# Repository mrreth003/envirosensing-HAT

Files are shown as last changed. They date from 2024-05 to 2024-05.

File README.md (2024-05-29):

# Envirosensing HAT PCB Design Group Project (EEE3088F)

## Design Team

- Ethan Morris (MRRETH003)
- Ethan Meknassi (MKNETH002)
- Moutloatsi Setlogelo (STLMOU001)

## Project Overview

Our project involves designing a proximity sensor surveillance device using a HAT (Hardware Attached on Top) powered by either a microcontroller or a battery. The HAT utilizes a PIR motion sensor to detect the presence of a person or animal, triggering a buzzer to sound an alert. Detection logs are stored and can be accessed by the user.

## Hardware Requirements

To operate this device, you will need the following hardware:
- **Power Source**: Either an STM32000 microcontroller or an 18650 battery.
- **USB Cable**: Male USB A to Male Micro USB B Cable for data retrieval.
- **Computer**: For data retrieval and battery charging.

## Hardware Setup

### Microcontroller Power Setup
1. Place the microcontroller under the device using the inner set of connectors.
2. Connect the 5V pin of the microcontroller to pin "J3" on the device. Pin "J3" is the leftmost pin on the third row of connectors when the device is in its default position (buzzer at the top left).

### Battery Power Setup
1. Insert the 18650 battery into the battery holder.
2. Connect the USB to Micro USB cable to the device and your computer for data retrieval or battery charging. The battery should be placed in the position indicated by the red rectangle in the attached picture.

## Basic Operating Instructions

1. Power on the device using the battery.
2. Create movement close to the device (e.g., wave your hand 5-10 cm away from the device). The buzzer should beep, indicating the device is operational.
3. To retrieve the detection log, connect the device to a computer using the USB to Micro USB cable.

## License

The license information for this project can be found in the Git repository.

[Project Repository](https://gitlab.com/mrreth003/envirosensing-hat/-/tree/main/)

Kind Regards,

Ethan Morris, Ethan Meknassi, and Moutloatsi Setlogelo

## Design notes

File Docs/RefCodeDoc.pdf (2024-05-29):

main class
Function | Description
MX_I2C2_Init(void) | Initializes the I2C communication port, lines and respective pins. I2C Channel 2 used to communicate with the Ambient Light Sensor with port B, pin 11 as the SDA line & port B, pin 10 as the SCL line
MX_GPIO_Init(void) | Initializes the GPIO Configuration. GPIO port C, pin 15 set to output mode.
MX_ADC_Init(void) | Initializes the ADC Configuration. Port C, pin 15 configured to ADC input
SystemClock_Config(void) | Configuration of the system clock.
MX_TIM2_Init(void) | Initializes the Timer Configuration channels for PWM generation. Port A, pin 1 used to generate pwm signal.
MX_USART1_UART_Init(void) | Initializes the USART Configuration. Port A, pin 10 set to Rx line & port A, pin 9 set to Tx line.
debugPrintln(UART_HandleTypeDef *uart_handle, char _out[]) : void | This function is used to send text data to the USB-COM port of the computer via the debug adapter. It has the following attributes: a pointer to the UART instance to write data, the output string in the form of a char and also it terminates the string using newline and carriage return commands.
main(void) | Houses and allows for execution of other functions. Allows for modulation within the code structure, improving debugging capabilities.
Error_Handler(void) | This function is executed in case of error occurrence.
assert_failed(uint8_t *file, uint32_t line) | User can add his own implementation to report the file name and line number.

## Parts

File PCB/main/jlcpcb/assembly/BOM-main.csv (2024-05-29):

Comment | Designator | Footprint | LCSC
2.2uH | L1 | L_0805_2012Metric | C1043
Buzzer | BZ1 | SPKR_PKM13EPYH4002-B0 | C128650
USB_B_Micro | J5 | USB_Micro-B_Molex-105133-0031 | C132563
TLV70012_SOT23-5 | U4 | SOT-23-5 | C134139
10uF | C8 | C_1206_3216Metric | C13585
TPS61230DRC | U3 | Texas_S-PVSON-N10_ThermalVias | C139626
CH340G | U10 | SOIC-16_3.9x9.9mm_P1.27mm | C14267
100nF | C20,C30,C31,C32,C33,C34,C35,C36 | C_0603_1608Metric | C14663
1u | C10,C7,C9 | C_0603_1608Metric | C15849
1k | R15,R16 | R_0805_2012Metric | C17513
100k | R17,R18 | R_1206_3216Metric | C17900
NPN | Q5 | SOT-23 | C20526
AO3400A | Q6 | SOT-23 | C20917
13k | R23 | R_0603_1608Metric | C22797
1M | R5 | R_0603_1608Metric | C22935
2k | R24 | R_0603_1608Metric | C22975
4K7 | R20,R22 | R_0603_1608Metric | C23162
10k | R2,R4 | R_0603_1608Metric | C25804
MAX232 | U11 | SOIC-16_3.9x9.9mm_P1.27mm | C26860
4.7uF | C1,C3,C5 | C_1206_3216Metric | C29823
LTC4054ES5-4.2 | U1 | TSOT-23-5 | C32574
LTR-553ALS-01 | U8 | LTR553ALS01 | C492375
10nF | C28,C29,C6 | C_0603_1608Metric | C57112
AT24C256C-SSHL-T | U9 | SOIC-8_3.9x4.9mm_P1.27mm | C6482
Q_PMOS_DSG | Q4 | SOT-23 | C8492
D_Schottky | D5 | D_SOD-323 | C8598
12MHz | Y1 | Crystal_SMD_3225-4Pin_3.2x2.5mm | C9002
Conn_01x33_Female | J1 | PinHeader_1x33_P2.54mm_Vertical
BK-18650-PC2 | BT1 | BAT_BK-18650-PC2
Conn_01x33_Female | J4 | PinHeader_1x33_P2.54mm_Vertical
Conn_01x33_Female | J2 | PinSocket_1x33_P2.54mm_Vertical
Conn_01x33_Female | J3 | PinSocket_1x33_P2.54mm_Vertical

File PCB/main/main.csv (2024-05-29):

Source: | C:\Users\ethan\OneDrive - University of Cape Town\2022\2022F\EEE3088F\Project\envirosensing-hat\PCB\main\main.kicad_sch
Date: | 08/04/2022 21:40:48
Tool: | Eeschema (6.0.2)
Generator: | C:\Program Files\KiCad\6.0\bin/bom_csv_grouped_by_value_with_fp1.py
Component Count: | 49
Ref | Qnty | Value | Cmp Name | Cmp Number | Backup Cmp Number | Footprint | Description | Price
BT1, | 1 | BK-18650-PC2 | BK-18650-PC2 |  |  | BAT_BK-18650-PC2
BZ1, | 1 | Buzzer | PKM13EPYH4002-B0 | C128650 | C96061 | PKM13EPYH4002-B0:SPKR_PKM13EPYH4002-B0 |  | 0.3955
C1, C3, C5, | 3 | 4.7uF | C_Small | C29823 | C1779 | Capacitor_SMD:C_1206_3216Metric | Unpolarized capacitor, small symbol | 0.0657
C6, C28, C29, | 3 | 10nF | C_Small | C57112 | C124567 | Capacitor_SMD:C_0603_1608Metric | Unpolarized capacitor, small symbol | 0.0028
C7, | 1 | 1uF | C_Small | C15849 | C90540 | Capacitor_SMD:C_0603_1608Metric | Unpolarized capacitor, small symbol | 0.0058
C8, | 1 | 10uF | C_Small | C13585 | C440198 | Capacitor_SMD:C_1206_3216Metric | Unpolarized capacitor, small symbol | 0.0427
C9, C10, | 2 | 1u | C_Small | C15849 | C1848 | Capacitor_SMD:C_0603_1608Metric | Unpolarized capacitor, small symbol | 0.0057
C20, C30, C31, C32, C33, C34, C35, C36, | 8 | 100nF | C_Small | C14663 | C30926 | Capacitor_SMD:C_0603_1608Metric | Unpolarized capacitor, small symbol | 0.0026
D5, | 1 | D_Schottky | D_Schottky | C8598 | C191023 | Diode_SMD:D_SOD-323 | Schottky diode | 0.046
J1, J4, | 2 | Conn_01x33_Female | Conn_01x33_Female |  |  | Connector_PinHeader_2.54mm:PinHeader_1x33_P2.54mm_Vertical | Generic connector, single row, 01x33, script generated (kicad-library-utils/schlib/autogen/connector/) | 0
J2, J3, | 2 | Conn_01x33_Female | Conn_01x33_Female |  |  | Connector_PinSocket_2.54mm:PinSocket_1x33_P2.54mm_Vertical | Generic connector, single row, 01x33, script generated (kicad-library-utils/schlib/autogen/connector/) | 0
J5, | 1 | USB_B_Micro | USB_B_Micro | C132563 | C136001 | Connector_USB:USB_Micro-B_Molex-105133-0031 | USB Micro Type B connector | 0.2511
L1, | 1 | 2.2uH | L | C1043 | C275345 | Inductor_SMD:L_0805_2012Metric | Inductor | 0.0079
Q4, | 1 | Q_PMOS_DSG | Q_PMOS_DSG | C8492 | C411713 | Package_TO_SOT_SMD:SOT-23 | P-MOSFET transistor, drain/source/gate | 0.0316
Q5, | 1 | NPN | Q_NPN_BCE | C20526 | C2146 | Package_TO_SOT_SMD:SOT-23 | NPN transistor, base/collector/emitter | 0.0143
Q6, | 1 | AO3400A | 2N7002 | C20917 | C15127 | Package_TO_SOT_SMD:SOT-23 | 0.115A Id, 60V Vds, N-Channel MOSFET, SOT-23 | 0.1313
R2, R4, | 2 | 10k | R_Small | C25804 | C23192 | Resistor_SMD:R_0603_1608Metric | Resistor, small symbol | 0.0013
R5, | 1 | 1M | R_Small | C22935 | C26098 | Resistor_SMD:R_0603_1608Metric | Resistor, small symbol | 0.0013
R15, R16, | 2 | 1k | R_Small | C17513 | C25623 | Resistor_SMD:R_0805_2012Metric | Resistor, small symbol | 0.0023
R17, R18, | 2 | 100k | R_Small | C17900 | C25741 | Resistor_SMD:R_1206_3216Metric | Resistor, small symbol | 0.004
R20, R22, | 2 | 4K7 | R_Small | C23162 | C17673 | Resistor_SMD:R_0603_1608Metric | Resistor, small symbol | 0.0083
R23, | 1 | 13k | R_Small_US | C22797 | C17455 | Resistor_SMD:R_0603_1608Metric | Resistor, small US symbol | 0.0013
R24, | 1 | 2k | R_Small_US | C22975 | C25590 | Resistor_SMD:R_0603_1608Metric | Resistor, small US symbol | 0.0014
U1, | 1 | LTC4054ES5-4.2 | LTC4054ES5-4.2 | C32574 |  | Package_TO_SOT_SMD:TSOT-23-5 | Constant-current/constant-voltage linear charger for single cell lithium-ion batteries with 2.9V Trickle Charge, 4.5V to 6.5V VDD, -40 to +85 degree Celcius, TSOT-23-5 | 0.1552
U3, | 1 | TPS61230DRC | TPS61230DRC | C139626 | C139626 | Package_SON:Texas_S-PVSON-N10_ThermalVias | High Efficiency Synchronous Step Up Converters with 5-A Switches, 2.3-5.5V Input Voltage, VSON-10 | 3.0442
U4, | 1 | TLV70012_SOT23-5 | TLV70012_SOT23-5 | C134139 |  | Package_TO_SOT_SMD:SOT-23-5 | 200mA Low Dropout Voltage Regulator, Fixed Output 1.2V, SOT-23-5 | 0.1672
U8, | 1 | LTR-553ALS-01 | LTR-553ALS-01 | C492375 | C78465 | LTR-553ALS-01:LTR553ALS01 | Light to Digital Converters Ambient Light Photo Sensor | 0.3374
U9, | 1 | AT24C256C-SSHL-T | AT24CS02-XHM | C6482 | C12371 | Package_SO:SOIC-8_3.9x4.9mm_P1.27mm | I2C Serial EEPROM, 2Kb (256x8) with Unique Serial Number, TSSOP8 | 1.5556
U10, | 1 | CH340G | CH340G | C14267 |  | Package_SO:SOIC-16_3.9x9.9mm_P1.27mm | USB serial converter, UART, SOIC-16 | 0.5838
U11, | 1 | MAX232 | MAX232 | C26860 | C158068 | Package_SO:SOIC-16_3.9x9.9mm_P1.27mm | Dual RS232 driver/receiver, 5V supply, 120kb/s, 0C-70C | 1.1443
Y1, | 1 | 12MHz | Crystal_Small | C9002 | C258939 | Crystal:Crystal_SMD_3225-4Pin_3.2x2.5mm | Two pin crystal, small symbol | 0.1007

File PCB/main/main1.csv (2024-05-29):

Source: | C:\Users\ethan\OneDrive - University of Cape Town\2022\2022F\EEE3088F\Project\envirosensing-hat\PCB\main\main.kicad_sch
Date: | 18/03/2022 08:45
Tool: | Eeschema (6.0.2)
Generator: | C:\Program Files\KiCad\6.0\bin/bom_csv_grouped_by_value_with_fp1.py
Component Count: | 95
Ref | Qnty | Value | Cmp Name | Cmp Number | Backup Cmp Number | Footprint | Description | Price
BZ1, | 1 | Buzzer | Buzzer | C128650 | C91080 | Buzzer_Beeper:Buzzer_Murata_PKMCS0909E | Buzzer, polarized | 0.3955 | 0.3955
 |  |  |  |  |  |  |  |  | 0
C1, C9, | 2 | 10nF | CAP | C57112 | C1710 | Capacitor_SMD:C_0603_1608Metric | Capacitor symbol for simulation only | 0.0028 | 0.0056
 |  |  |  |  |  |  |  |  | 0
C2, C3, C4, C5, | 4 | 1u | C_Small | C15849 | C1848 | Capacitor_SMD:C_0603_1608Metric | Unpolarized capacitor, small symbol | 0.0057 | 0.0228
 |  |  |  |  |  |  |  |  | 0
C6, C11, | 2 | 22uF | CAP | C59461 | C1532 | Capacitor_SMD:C_0603_1608Metric | Capacitor symbol for simulation only | 0.0098 | 0.0196
 |  |  |  |  |  |  |  |  | 0
C7, | 1 | 1uF | C_Small | C15849 | C28323 | Capacitor_SMD:C_0603_1608Metric | Unpolarized capacitor, small symbol | 0.0057 | 0.0057
 |  |  |  |  |  |  |  |  | 0
C8, | 1 | 22nF | C_Small | C21122 | C123507 | Capacitor_SMD:C_0603_1608Metric | Unpolarized capacitor, small symbol | 0.0059 | 0.0059
 |  |  |  |  |  |  |  |  | 0
C10, C14, | 2 | 47nF | CAP | C1622 | C53134 | Capacitor_SMD:C_0603_1608Metric | Capacitor symbol for simulation only | 0.0048 | 0.0096
 |  |  |  |  |  |  |  |  | 0
C12, | 1 | 3.3nF | CAP | C1613 | C53175 | Capacitor_SMD:C_0603_1608Metric | Capacitor symbol for simulation only | 0.0067 | 0.0067
 |  |  |  |  |  |  |  |  | 0
C13, C16, | 2 | 10uF | C_Small | C13585 | C440198 | Capacitor_SMD:C_0805_2012Metric | Unpolarized capacitor, small symbol | 0.0427 | 0.0854
 |  |  |  |  |  |  |  |  | 0
C15, C17, C18, C19, C20, C21, C22, C23, C24, | 9 | 100nF | C_Small | C14663 | C30926 | Capacitor_SMD:C_0603_1608Metric | Unpolarized capacitor, small symbol | 0.0026 | 0.0234
 |  |  |  |  |  |  |  |  | 0
C25, | 1 | 4.7uF | C_Small | C98192 | C215908 | Capacitor_SMD:C_0805_2012Metric | Unpolarized capacitor, small symbol | 0.0293 | 0.0293
 |  |  |  |  |  |  |  |  | 0
D1, D4, D7, D8, D11, D12, D13, D14, | 8 | LED | LED | C2296 | C84256 | Diode_SMD:D_0805_2012Metric | Light emitting diode | 0.0088 | 0.0704
 |  |  |  |  |  |  |  |  | 0
D2, D3, D5, D6, D9, | 5 | 1N5819 | 1N5819 | C84620 | C526214 | Diode_THT:D_DO-41_SOD81_P7.62mm_Horizontal | 40V 1A Schottky Barrier Rectifier Diode, DO-41 | 0.02732 | 0.1366
 |  |  |  |  |  |  |  |  | 0
D10, | 1 | DIODE | DIODE | C14538 | C14516 | Diode_THT:D_DO-35_SOD27_P2.54mm_Vertical_AnodeUp | Diode symbol for simulation only. Pin order incompatible with official kicad footprints | 0.0083 | 0.0083
 |  |  |  |  |  |  |  |  | 0
J1, J4, | 2 | Conn_01x33_Female | Conn_01x33_Female |  |  | Connector_PinHeader_2.54mm:PinHeader_1x33_P2.54mm_Vertical | Generic connector, single row, 01x33, script generated (kicad-library-utils/schlib/autogen/connector/) | 0 | 0
 |  |  |  |  |  |  |  |  | 0
J2, J3, | 2 | Conn_01x33_Female | Conn_01x33_Female | C1234 (example) | C12345 (example) | Connector_PinSocket_2.54mm:PinSocket_1x33_P2.54mm_Vertical | Generic connector, single row, 01x33, script generated (kicad-library-utils/schlib/autogen/connector/) | 0 | 0
 |  |  |  |  |  |  |  |  | 0
J5, | 1 | USB_B_Micro | USB_B_Micro | C132563 | C136001 | Connector_USB:USB_Micro-B_Molex-105133-0031 | USB Micro Type B connector | 0.2511 | 0.2511
 |  |  |  |  |  |  |  |  | 0
JP1, JP2, JP3, JP4, JP5, JP6, JP7, JP8, | 8 | Jumper_2_Bridged | Jumper_2_Bridged | C390678 | C24980 | Connector_PinHeader_2.54mm:PinHeader_1x02_P2.54mm_Vertical | Jumper, 2-pole, closed/bridged | 0.007 | 0.056
 |  |  |  |  |  |  |  |  | 0
Q1, Q3, | 2 | S8550 | S8550 | C105432 | C8542 | Package_TO_SOT_THT:TO-92_Inline | 0.7A Ic, 20V Vce, Low Voltage High Current PNP Transistor, TO-92 | 0.021 | 0.042
 |  |  |  |  |  |  |  |  | 0
Q2, | 1 | Q_PMOS_GDS | Q_PMOS_GDS | C127863 | C130106 | Package_TO_SOT_SMD:TO-252-2 | P-MOSFET transistor, gate/drain/source | 0.2157 | 0.2157
 |  |  |  |  |  |  |  |  | 0
Q4, | 1 | NPN | Q_NPN_BCE | C305395 | C118538 | Package_TO_SOT_THT:TO-92 | NPN transistor, base/collector/emitter | 0.0129 | 0.0129
 |  |  |  |  |  |  |  |  | 0
Q5, | 1 | 2N7002 | 2N7002 | C107290 | C9114 | Package_TO_SOT_THT:TO-92 | 0.115A Id, 60V Vds, N-Channel MOSFET, SOT-23 | 0.0427 | 0.0427
 |  |  |  |  |  |  |  |  | 0
R1, R18, | 2 | 10K | R_Small | C25804 | C23192 | Resistor_SMD:R_0603_1608Metric | Resistor, small symbol | 0.0013 | 0.0026
 |  |  |  |  |  |  |  |  | 0
R2, | 1 | 100K | R_Small | C17900 | C25741 | Resistor_SMD:R_1206_3216Metric | Resistor, small symbol | 0.004 | 0.004
 |  |  |  |  |  |  |  |  | 0
R3, R4, R19, R21, | 4 | 4K7 | R_Small | C23162 | C17673 | Resistor_SMD:R_0603_1608Metric | Resistor, small symbol | 0.0083 | 0.0332
 |  |  |  |  |  |  |  |  | 0
R5, R8, | 2 | 13k | R_Small | C22797 | C17455 | Resistor_SMD:R_0603_1608Metric_Pad0.98x0.95mm_HandSolder | Resistor, small symbol | 0.0013 | 0.0026
 |  |  |  |  |  |  |  |  | 0
R6, | 1 | 56k | R_Small | C23206 | C17756 | Resistor_SMD:R_0603_1608Metric | Resistor, small symbol | 0.0013 | 0.0013
 |  |  |  |  |  |  |  |  | 0
R7, R9, | 2 | 680k | R_Small | C25822 | C17797 | Resistor_SMD:R_0603_1608Metric_Pad0.98x0.95mm_HandSolder | Resistor, small symbol | 0.0013 | 0.0026
 |  |  |  |  |  |  |  |  | 0
R10, R13, | 2 | 220k | R_Small | C22961 | C17556 | Resistor_SMD:R_0603_1608Metric | Resistor, small symbol | 0.0014 | 0.0028
 |  |  |  |  |  |  |  |  | 0
R11, R12, | 2 | 470k | R_Small | C17709 | C17675 | Resistor_SMD:R_0805_2012Metric | Resistor, small symbol | 0.0028 | 0.0056
 |  |  |  |  |  |  |  |  | 0
R14, R15, | 2 | 1k | R_Small | C17513 | C25623 | Resistor_SMD:R_0805_2012Metric_Pad1.20x1.40mm_HandSolder | Resistor, small symbol | 0.0023 | 0.0046
 |  |  |  |  |  |  |  |  | 0
R16, R17, | 2 | 100k | R_Small | C17513 | C25623 | Resistor_SMD:R_0805_2012Metric_Pad1.20x1.40mm_HandSolder | Resistor, small symbol | 0.0023 | 0.0046
 |  |  |  |  |  |  |  |  | 0
R20, | 1 | 470 | R_Small | C17710 | C23179 | Resistor_SMD:R_0805_2012Metric | Resistor, small symbol | 0.0025 | 0.0025
 |  |  |  |  |  |  |  |  | 0
R22, R23, | 2 | 2K2 | R_Small | C4190 | C17520 | Resistor_SMD:R_0603_1608Metric | Resistor, small symbol | 0.0013 | 0.0026
 |  |  |  |  |  |  |  |  | 0
R24, R25, | 2 | 270 | R_Small | C17710 | C23179 | Resistor_SMD:R_0805_2012Metric | Resistor, small symbol | 0.0025 | 0.005
 |  |  |  |  |  |  |  |  | 0
TP1, TP2, TP3, TP4, | 4 | TestPoint | TestPoint | C238127 | C238124 | TestPoint:TestPoint_Loop_D2.60mm_Drill1.6mm_Beaded | test point | 0.4123 | 1.6492
 |  |  |  |  |  |  |  |  | 0
U1, | 1 | LM7805_TO220 | LM7805_TO220 | C71107 | C507145 | Package_TO_SOT_THT:TO-220-3_Vertical | Positive 1A 35V Linear Regulator, Fixed Output 5V, TO-220 | 0.3143 | 0.3143
 |  |  |  |  |  |  |  |  | 0
U2, | 1 | TLV70012_SOT23-5 | TLV70012_SOT23-5 | C69446 |  | Package_TO_SOT_SMD:SOT-23-5 | 200mA Low Dropout Voltage Regulator, Fixed Output 1.2V, SOT-23-5 | 1.838 | 1.838
 |  |  |  |  |  |  |  |  | 0
U3, | 1 | PIR Sensor | A1367xKTTN-10 | C98110 | C139580 | Package_TO_SOT_THT:TO-5-3_Window | Programmable Linear Hall Effect Sensor, +6.4 to +14mV/G, SIP-4 | 1.0152 | 1.0152
 |  |  |  |  |  |  |  |  | 0
U4, | 1 | COS724 | Opamp_Quad | C2685541 | C125823 | Package_SO:TSSOP-14_4.4x5mm_P0.65mm | Quad operational amplifier | 0.3387 | 0.3387
 |  |  |  |  |  |  |  |  | 0
U5, | 1 | 74LS00 | 74LS00 | C282334 | C150244 | Package_TO_SOT_SMD:SOT-353_SC-70-5 | quad 2-input NAND gate | 0.2809 | 0.2809
 |  |  |  |  |  |  |  |  | 0
U6, | 1 | VEML6040 | APDS-9306-065 | C78465 | C2688732 | OptoDevice:AMS_TSL2550_SMD | Ambient Light Sensor, I2C interface, 1.7-3.6V, DFN-6 | 2.5708 | 2.5708
 |  |  |  |  |  |  |  |  | 0
U7, | 1 | AT24C256C-SSHL-T | AT24CS02-XHM | C6482 | C12371 | Package_SO:SOIC-8_3.9x4.9mm_P1.27mm | I2C Serial EEPROM, 2Kb (256x8) with Unique Serial Number, TSSOP8 | 1.5556 | 1.5556
 |  |  |  |  |  |  |  |  | 0
U8, | 1 | FT232RL | FT232RL | C8690 |  | Package_SO:SSOP-28_5.3x10.2mm_P0.65mm | USB to Serial Interface, SSOP-28 | 6.6312 | 6.6312
 |  |  |  |  |  |  |  | 16.09592 | 17.7131

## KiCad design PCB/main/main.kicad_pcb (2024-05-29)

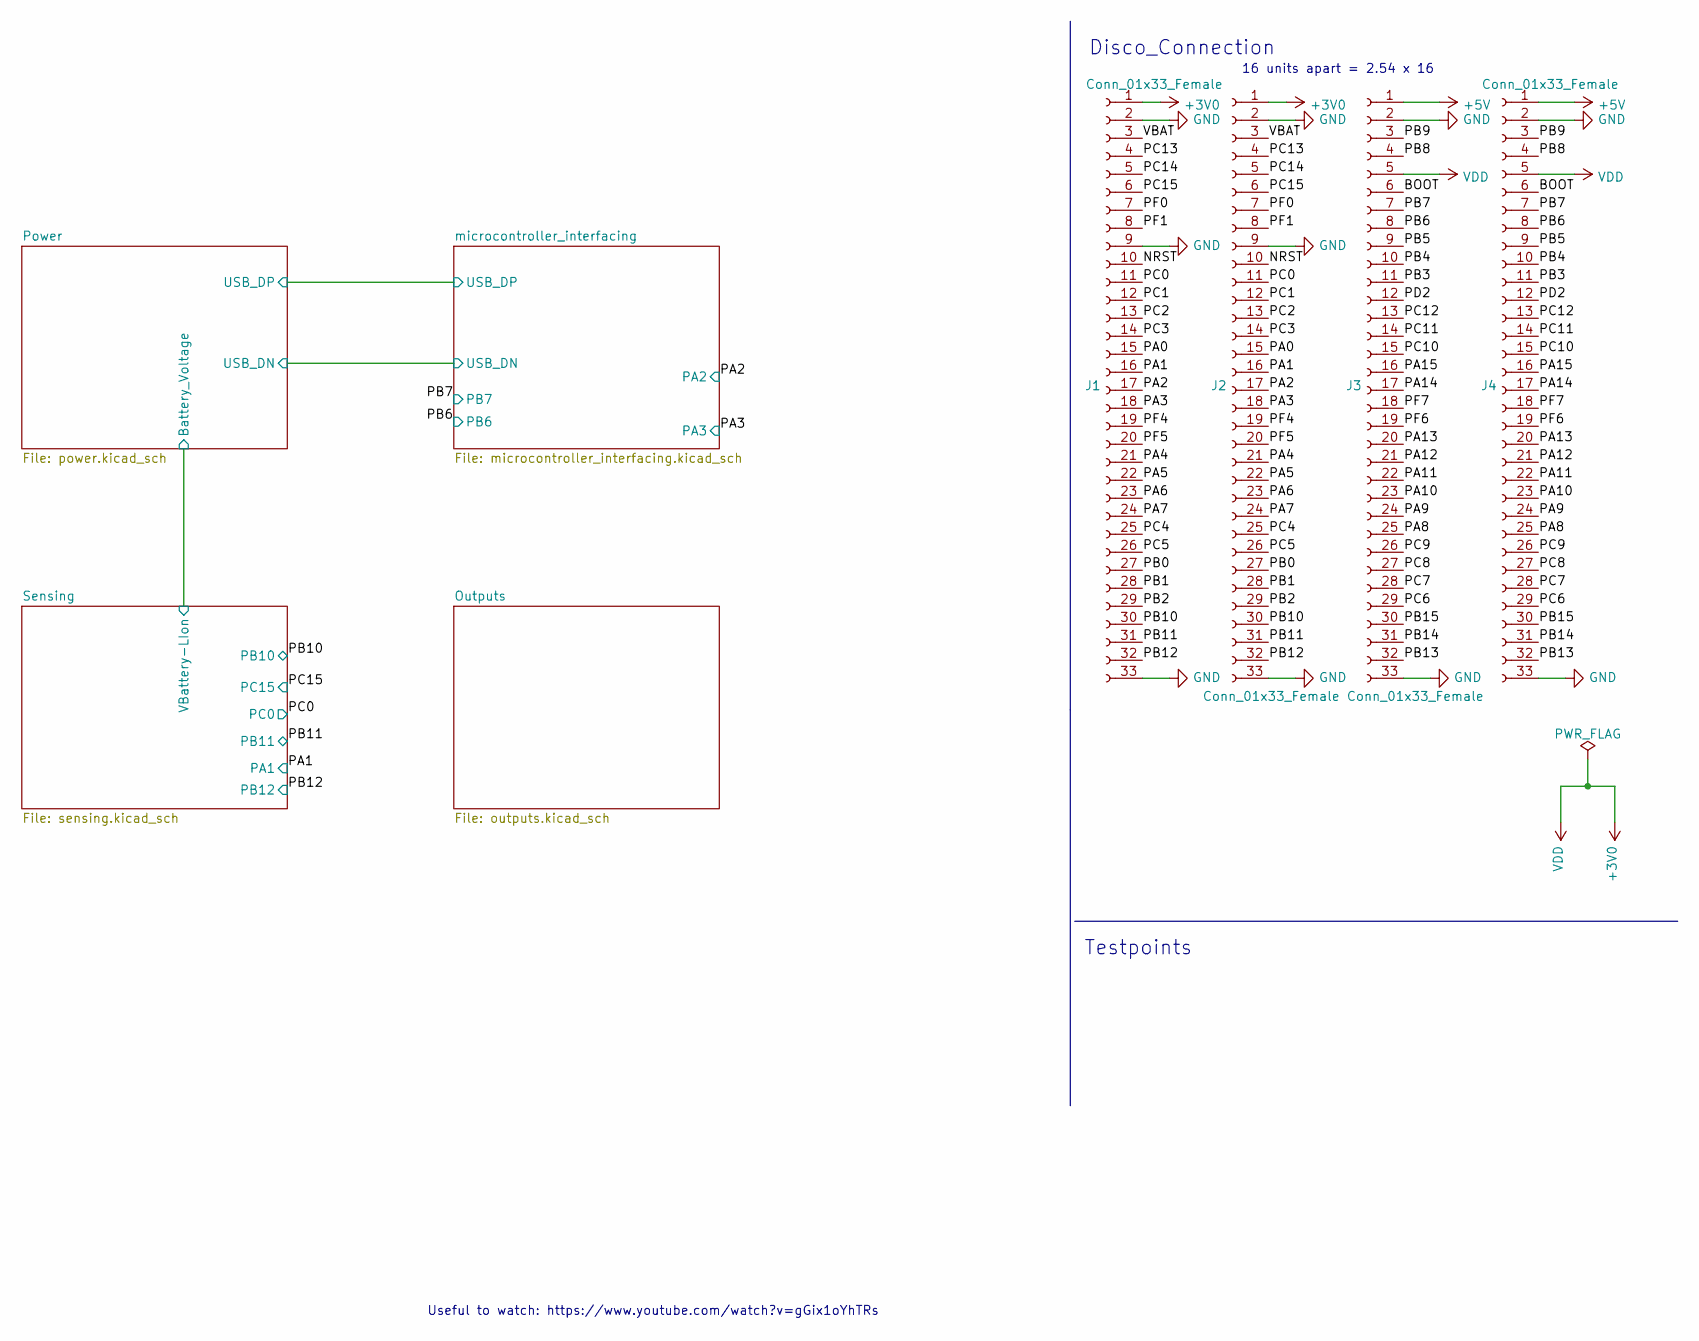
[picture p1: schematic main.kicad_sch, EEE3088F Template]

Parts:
J1, J4: Conn_01x33_Female; PinHeader_1x33_P2.54mm_Vertical
J2, J3: Conn_01x33_Female; PinSocket_1x33_P2.54mm_Vertical

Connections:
+3V0: J1.1, J2.1, J3.5, J4.5
+5V: J3.1, J4.1; also elsewhere on the board
/BOOT: J3.6, J4.6
/NRST: J1.10, J2.10
/PA0: J1.15, J2.15
/PA1: J1.16, J2.16; also elsewhere on the board
/PA2: J1.17, J2.17; also elsewhere on the board
/PA3: J1.18, J2.18; also elsewhere on the board
/PA4: J1.21, J2.21
/PA5: J1.22, J2.22
/PA6: J1.23, J2.23
/PA7: J1.24, J2.24
/PA8: J3.25, J4.25
/PA9: J3.24, J4.24
/PA10: J3.23, J4.23
/PA11: J3.22, J4.22
/PA12: J3.21, J4.21
/PA13: J3.20, J4.20
/PA14: J3.17, J4.17
/PA15: J3.16, J4.16
/PB0: J1.27, J2.27
/PB1: J1.28, J2.28
/PB2: J1.29, J2.29
/PB3: J3.11, J4.11
/PB4: J3.10, J4.10
/PB5: J3.9, J4.9
/PB6: J3.8, J4.8; also elsewhere on the board
/PB7: J3.7, J4.7; also elsewhere on the board
/PB8: J3.4, J4.4
/PB9: J3.3, J4.3
/PB10: J1.30, J2.30; also elsewhere on the board
/PB11: J1.31, J2.31; also elsewhere on the board
/PB12: J1.32, J2.32; also elsewhere on the board
/PB13: J3.32, J4.32
/PB14: J3.31, J4.31
/PB15: J3.30, J4.30
/PC0: J1.11, J2.11; also elsewhere on the board
/PC1: J1.12, J2.12
/PC2: J1.13, J2.13
/PC3: J1.14, J2.14
/PC4: J1.25, J2.25
/PC5: J1.26, J2.26
/PC6: J3.29, J4.29
/PC7: J3.28, J4.28
/PC8: J3.27, J4.27
/PC9: J3.26, J4.26
/PC10: J3.15, J4.15
/PC11: J3.14, J4.14
/PC12: J3.13, J4.13
/PC13: J1.4, J2.4
/PC14: J1.5, J2.5
/PC15: J1.6, J2.6; also elsewhere on the board
/PD2: J3.12, J4.12
/PF0: J1.7, J2.7
/PF1: J1.8, J2.8
/PF4: J1.19, J2.19
/PF5: J1.20, J2.20
/PF6: J3.19, J4.19
/PF7: J3.18, J4.18
/VBAT: J1.3, J2.3
GND: J1.2, J1.9, J1.33, J2.2, J2.9, J2.33, J3.2, J3.33, J4.2, J4.33; also elsewhere on the board

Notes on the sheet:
Useful to watch: https://www.youtube.com/watch?v=gGix1oYhTRs
16 units apart = 2.54 x 16
Disco_Connection
Testpoints

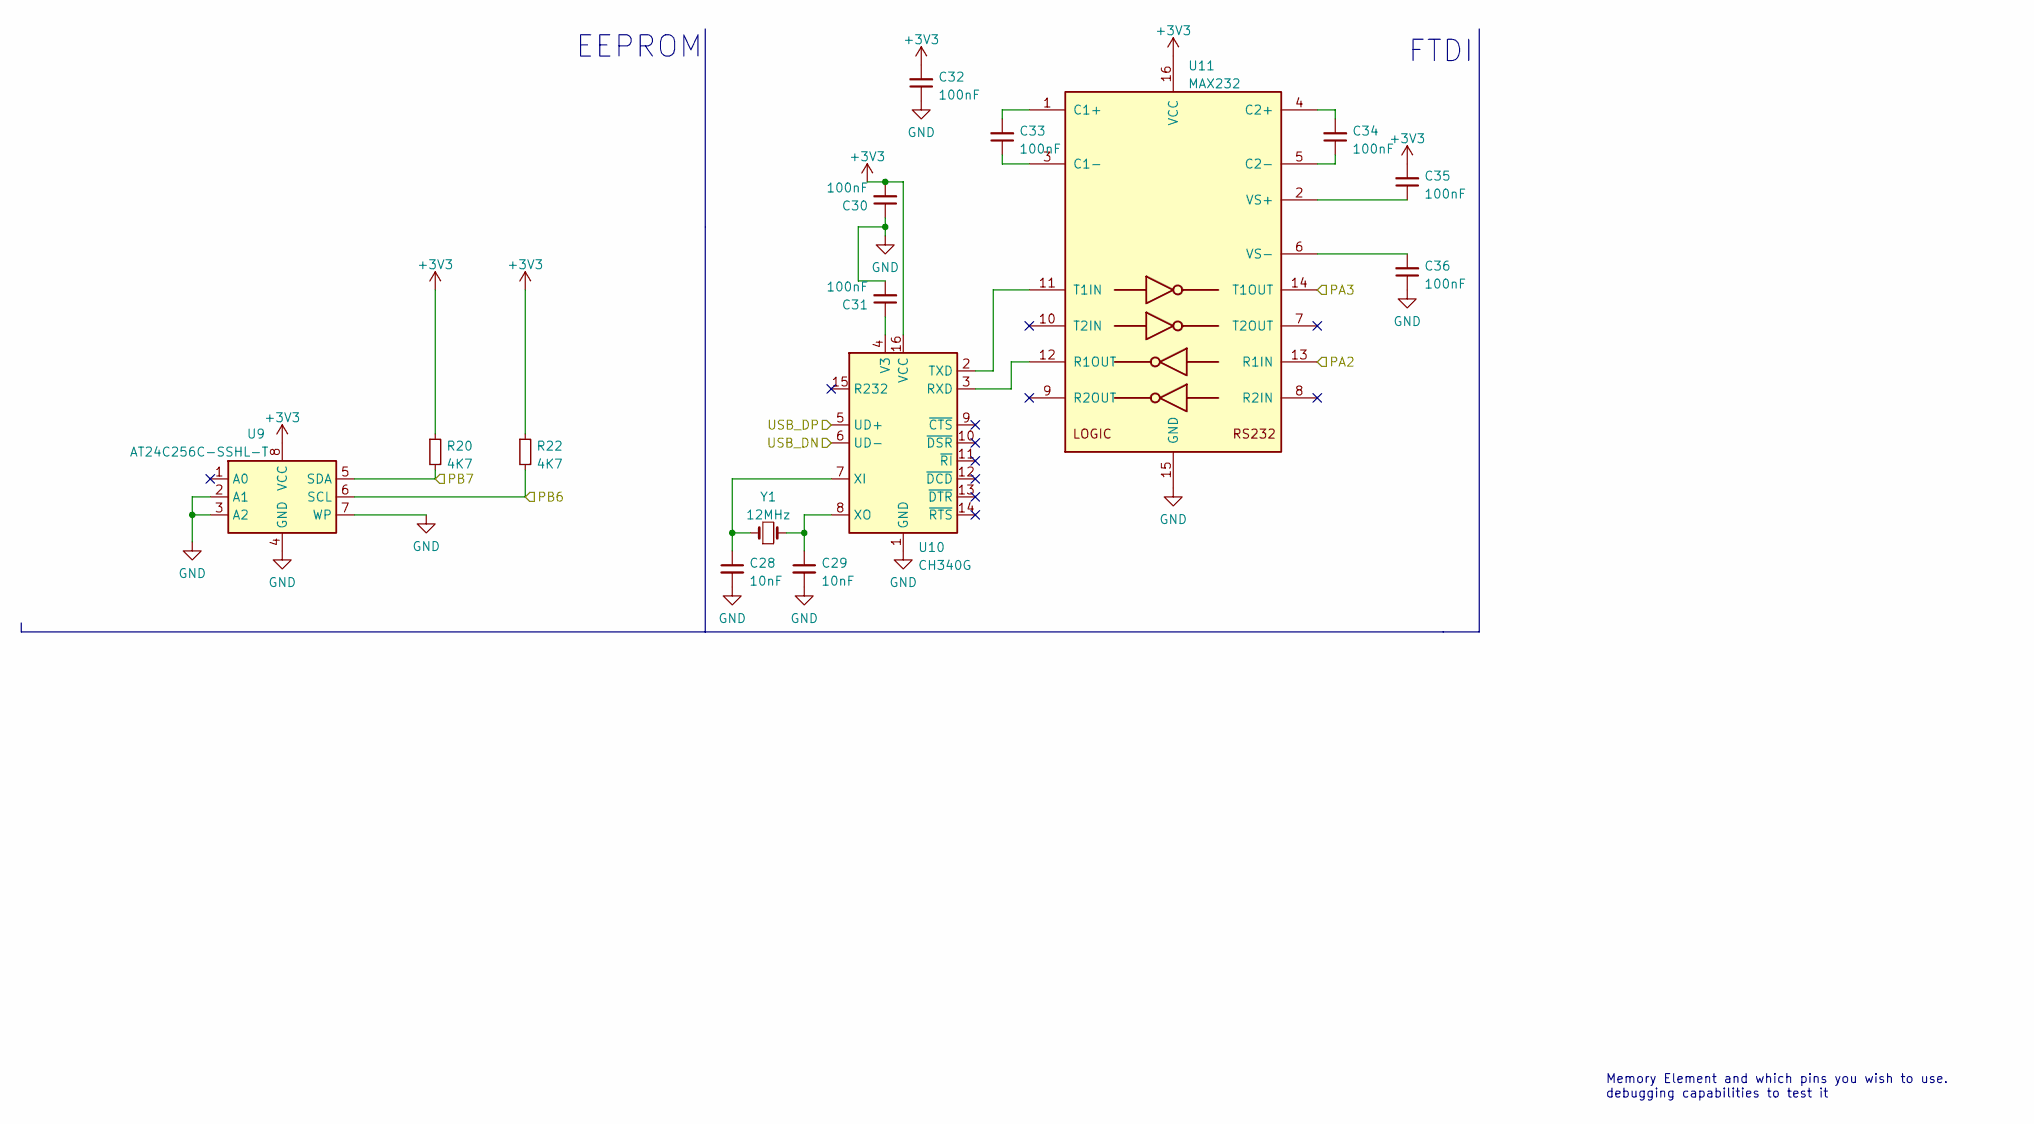
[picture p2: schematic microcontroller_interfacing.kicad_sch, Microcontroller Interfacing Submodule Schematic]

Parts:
C28, C29: 10nF; C_0603_1608Metric; LCSC C57112
C30, C31, C32, C33, C34, C35, C36: 100nF; C_0603_1608Metric; LCSC C14663
R20, R22: 4K7; R_0603_1608Metric; LCSC C23162
U9: AT24C256C-SSHL-T; SOIC-8_3.9x4.9mm_P1.27mm; LCSC C6482
U10: CH340G; SOIC-16_3.9x9.9mm_P1.27mm; LCSC C14267
U11: MAX232; SOIC-16_3.9x9.9mm_P1.27mm; LCSC C26860
Y1: 12MHz; Crystal_SMD_3225-4Pin_3.2x2.5mm; LCSC C9002

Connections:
+3V3: C30.2, C32.2, C35.2, R20.1, R22.1, U9.8 (VCC), U10.16 (VCC), U11.16 (VCC); also elsewhere on the board
/PA2: U11.13 (R1IN); also elsewhere on the board
/PA3: U11.14 (T1OUT); also elsewhere on the board
/PB6: R22.2, U9.6 (SCL); also elsewhere on the board
/PB7: R20.2, U9.5 (SDA); also elsewhere on the board
/Power/USB_DN: U10.6 (UD-); also elsewhere on the board
/Power/USB_DP: U10.5 (UD+); also elsewhere on the board
GND: C28.2, C29.2, C30.1, C31.2, C32.1, C36.1, U9.2 (A1), U9.3 (A2), U9.4 (GND), U9.7 (WP), U10.1 (GND), U11.15 (GND); also elsewhere on the board
unnamed: C28.1, U10.7 (XI), Y1.1
unnamed: C29.1, U10.8 (XO), Y1.2
unnamed: C31.1, U10.4 (V3)
unnamed: C33.1, U11.3 (C1-)
unnamed: C33.2, U11.1 (C1+)
unnamed: C34.1, U11.5 (C2-)
unnamed: C34.2, U11.4 (C2+)
unnamed: C35.1, U11.2 (VS+)
unnamed: C36.2, U11.6 (VS-)
unnamed: U10.2 (TXD), U11.11 (T1IN)
unnamed: U10.3 (RXD), U11.12 (R1OUT)

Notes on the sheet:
FTDI
EEPROM
Memory Element and which pins you wish to use. debugging capabilities to test it

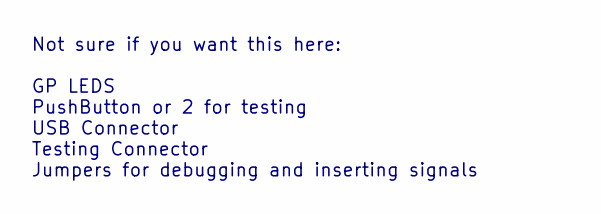
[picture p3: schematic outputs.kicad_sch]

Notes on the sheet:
Not sure if you want this here: GP LEDS PushButton or 2 for testing USB Connector Testing Connector Jumpers for debugging and inserting signals

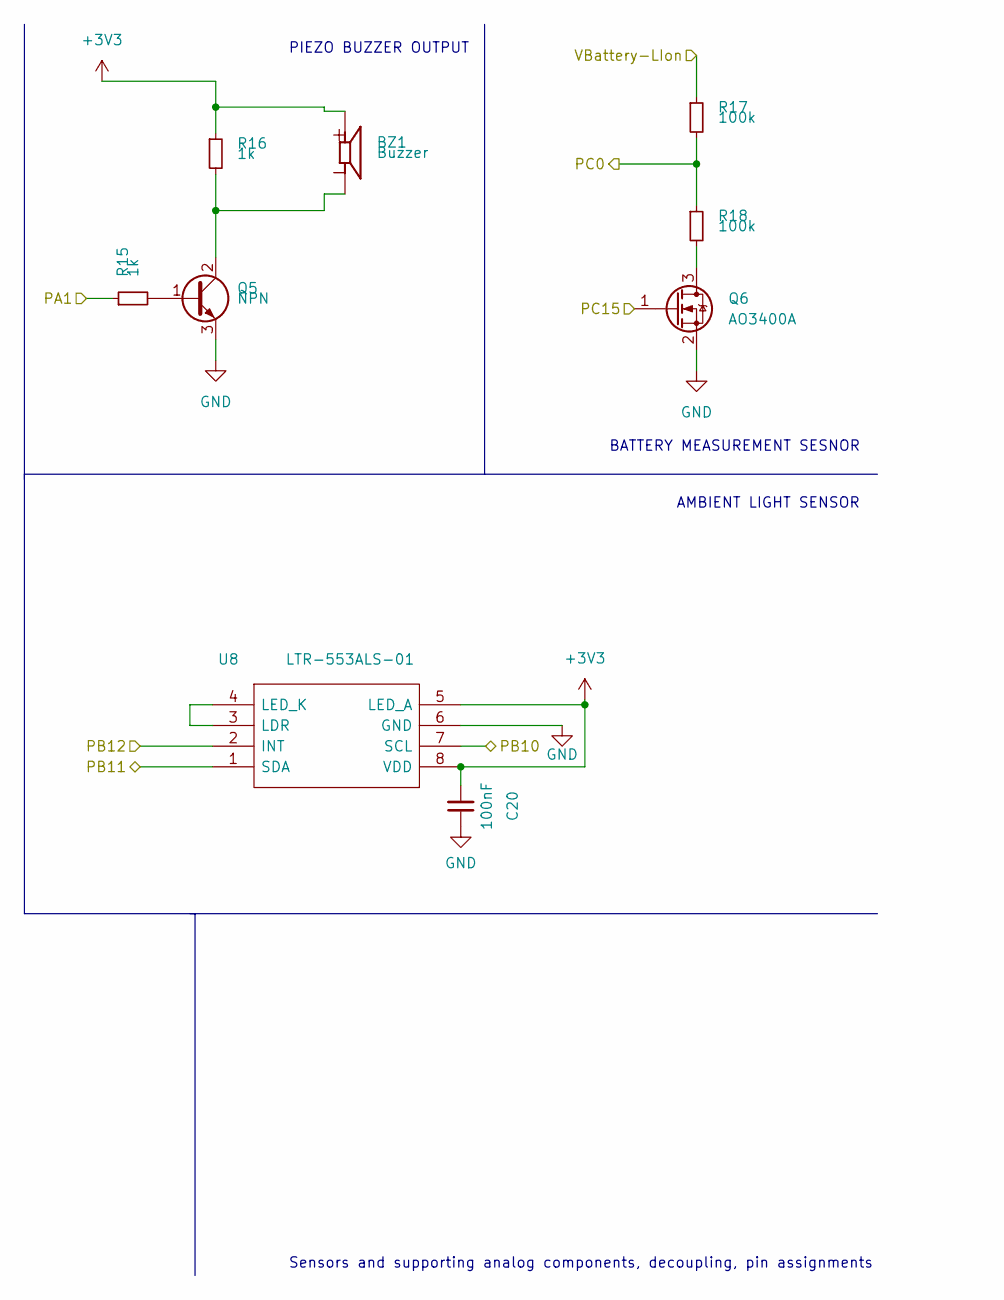
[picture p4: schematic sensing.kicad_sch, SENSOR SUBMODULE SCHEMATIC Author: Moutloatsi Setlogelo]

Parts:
BZ1: Buzzer; SPKR_PKM13EPYH4002-B0; LCSC C128650
C20: 100nF; C_0603_1608Metric; LCSC C14663
Q5: NPN; SOT-23; LCSC C20526
Q6: AO3400A; SOT-23; LCSC C20917
R15, R16: 1k; R_0805_2012Metric; LCSC C17513
R17, R18: 100k; R_1206_3216Metric; LCSC C17900
U8: LTR-553ALS-01; LTR553ALS01; LCSC C492375

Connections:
+3V3: BZ1.P, C20.2, R16.1, U8.5 (LED_A), U8.8 (VDD); also elsewhere on the board
/PA1: R15.1; also elsewhere on the board
/PB10: U8.7 (SCL); also elsewhere on the board
/PB11: U8.1 (SDA); also elsewhere on the board
/PB12: U8.2 (INT); also elsewhere on the board
/PC0: R17.2, R18.1; also elsewhere on the board
/PC15: Q6.1 (G); also elsewhere on the board
/Power/Battery_Voltage: R17.1; also elsewhere on the board
GND: C20.1, Q5.3 (E), Q6.2 (S), U8.6 (GND); also elsewhere on the board
unnamed: BZ1.N, Q5.2 (C), R16.2
unnamed: Q5.1 (B), R15.2
unnamed: Q6.3 (D), R18.2
unnamed: U8.3 (LDR), U8.4 (LED_K)

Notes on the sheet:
AMBIENT LIGHT SENSOR
Sensors and supporting analog components, decoupling, pin assignments
PIEZO BUZZER OUTPUT
BATTERY MEASUREMENT SESNOR

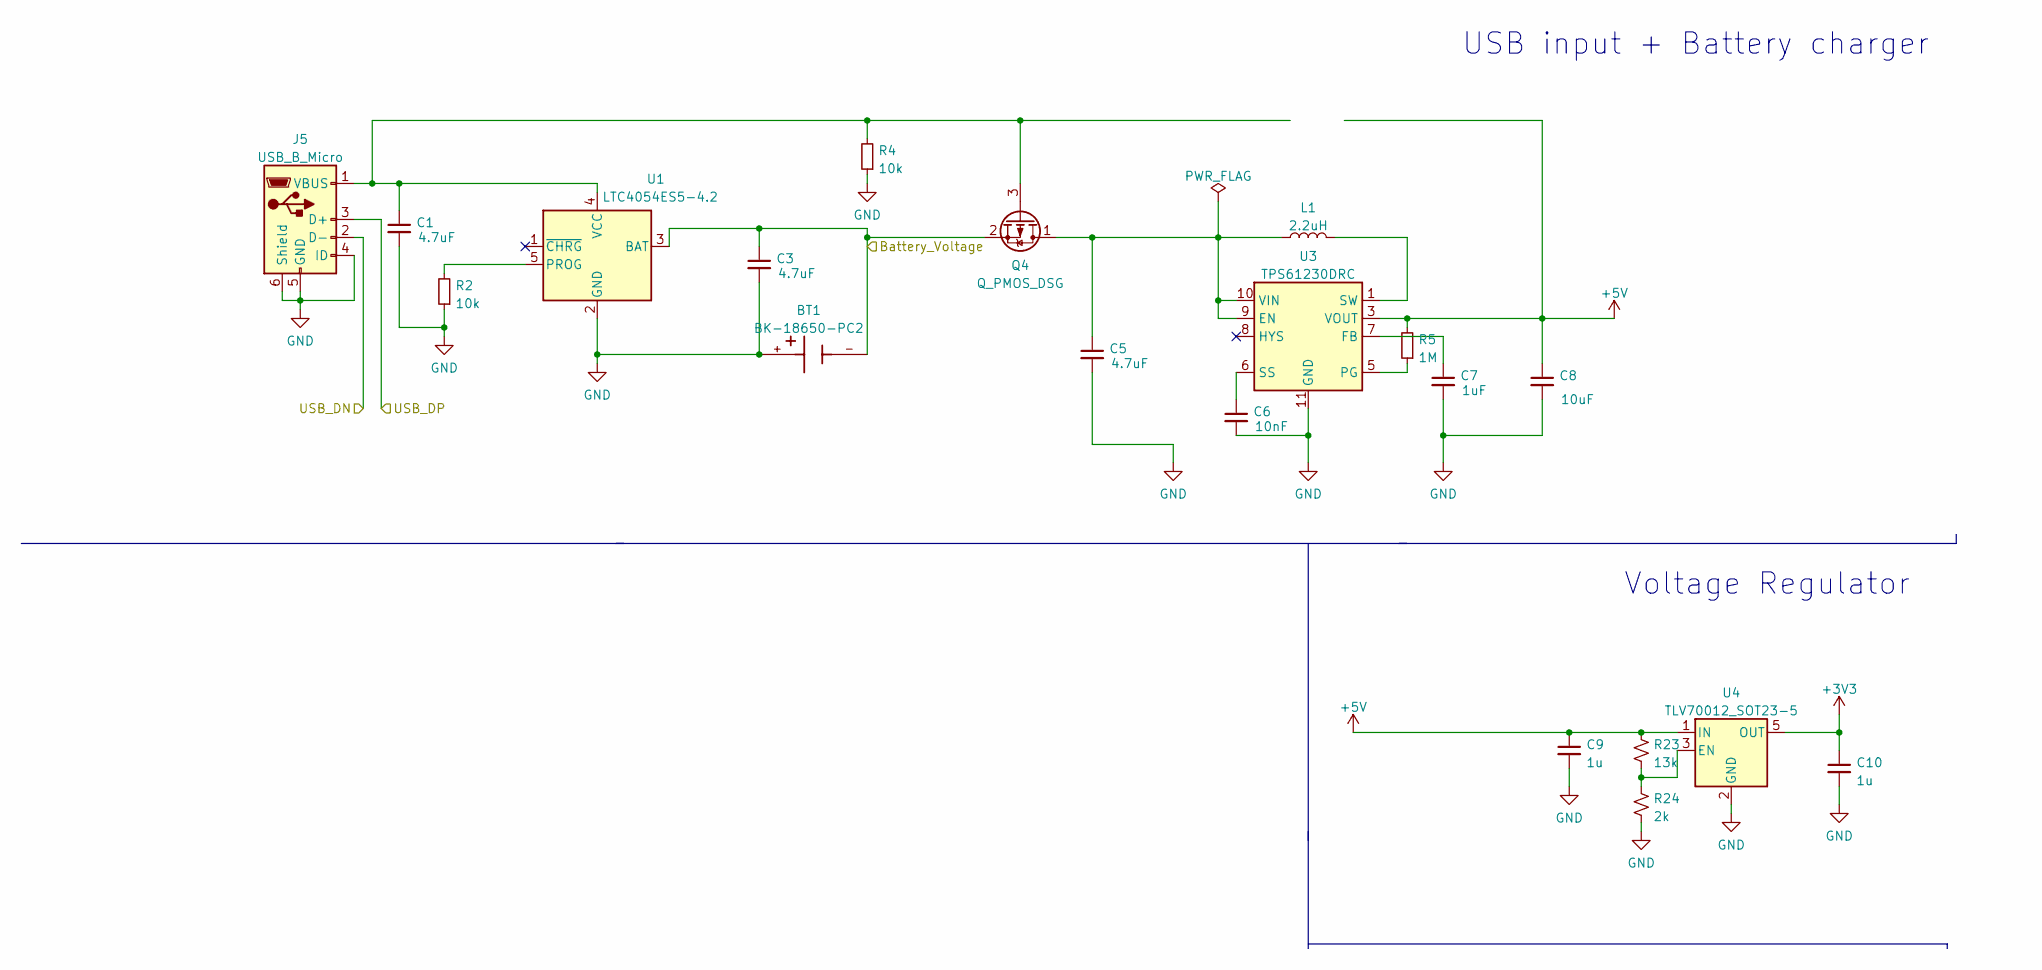
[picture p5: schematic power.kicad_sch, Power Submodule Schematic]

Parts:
BT1: BK-18650-PC2; BAT_BK-18650-PC2; PARTREV F
C1, C3, C5: 4.7uF; C_1206_3216Metric; LCSC C29823
C6: 10nF; C_0603_1608Metric; LCSC C57112
C7: 1uF; C_0603_1608Metric; LCSC C15849
C8: 10uF; C_1206_3216Metric; LCSC C13585
C9, C10: 1u; C_0603_1608Metric; LCSC C15849
J5: USB_B_Micro; USB_Micro-B_Molex-105133-0031; LCSC C132563
L1: 2.2uH; L_0805_2012Metric; LCSC C1043
Q4: Q_PMOS_DSG; SOT-23; LCSC C8492
R2, R4: 10k; R_0603_1608Metric; LCSC C25804
R5: 1M; R_0603_1608Metric; LCSC C22935
R23: 13k; R_0603_1608Metric; LCSC C22797
R24: 2k; R_0603_1608Metric; LCSC C22975
U1: LTC4054ES5-4.2; TSOT-23-5; LCSC C32574
U3: TPS61230DRC; Texas_S-PVSON-N10_ThermalVias; LCSC C139626
U4: TLV70012_SOT23-5; SOT-23-5; LCSC C134139

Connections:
+3V3: C10.1, U4.5 (OUT); also elsewhere on the board
+5V: C8.1, C9.1, R5.2, R23.1, U3.3 (VOUT), U3.4 (VOUT), U4.1 (IN); also elsewhere on the board
/Power/Battery_Voltage: BT1.-, C3.1, Q4.2 (S), U1.3 (BAT); also elsewhere on the board
/Power/USB_DN: J5.2 (D-); also elsewhere on the board
/Power/USB_DP: J5.3 (D+); also elsewhere on the board
GND: BT1.+, C1.2, C3.2, C5.2, C6.2, C7.2, C8.2, C9.2, C10.2, J5.4 (ID), J5.5 (GND), J5.6 (Shield), R2.1, R4.1, R24.2, U1.2 (GND), U3.11 (GND), U4.2 (GND); also elsewhere on the board
unnamed 66: C1.1, J5.1 (VBUS), Q4.3 (G), R4.2, U1.4 (VCC); also elsewhere on the board
unnamed: C5.1, L1.1, Q4.1 (D), U3.9 (EN), U3.10 (VIN)
unnamed: C6.1, U3.6 (SS)
unnamed: C7.1, U3.7 (FB)
unnamed: L1.2, U3.1 (SW), U3.2 (SW)
unnamed: R2.2, U1.5 (PROG)
unnamed: R5.1, U3.5 (PG)
unnamed: R23.2, R24.1, U4.3 (EN)

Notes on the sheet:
USB input + Battery charger
Voltage Regulator

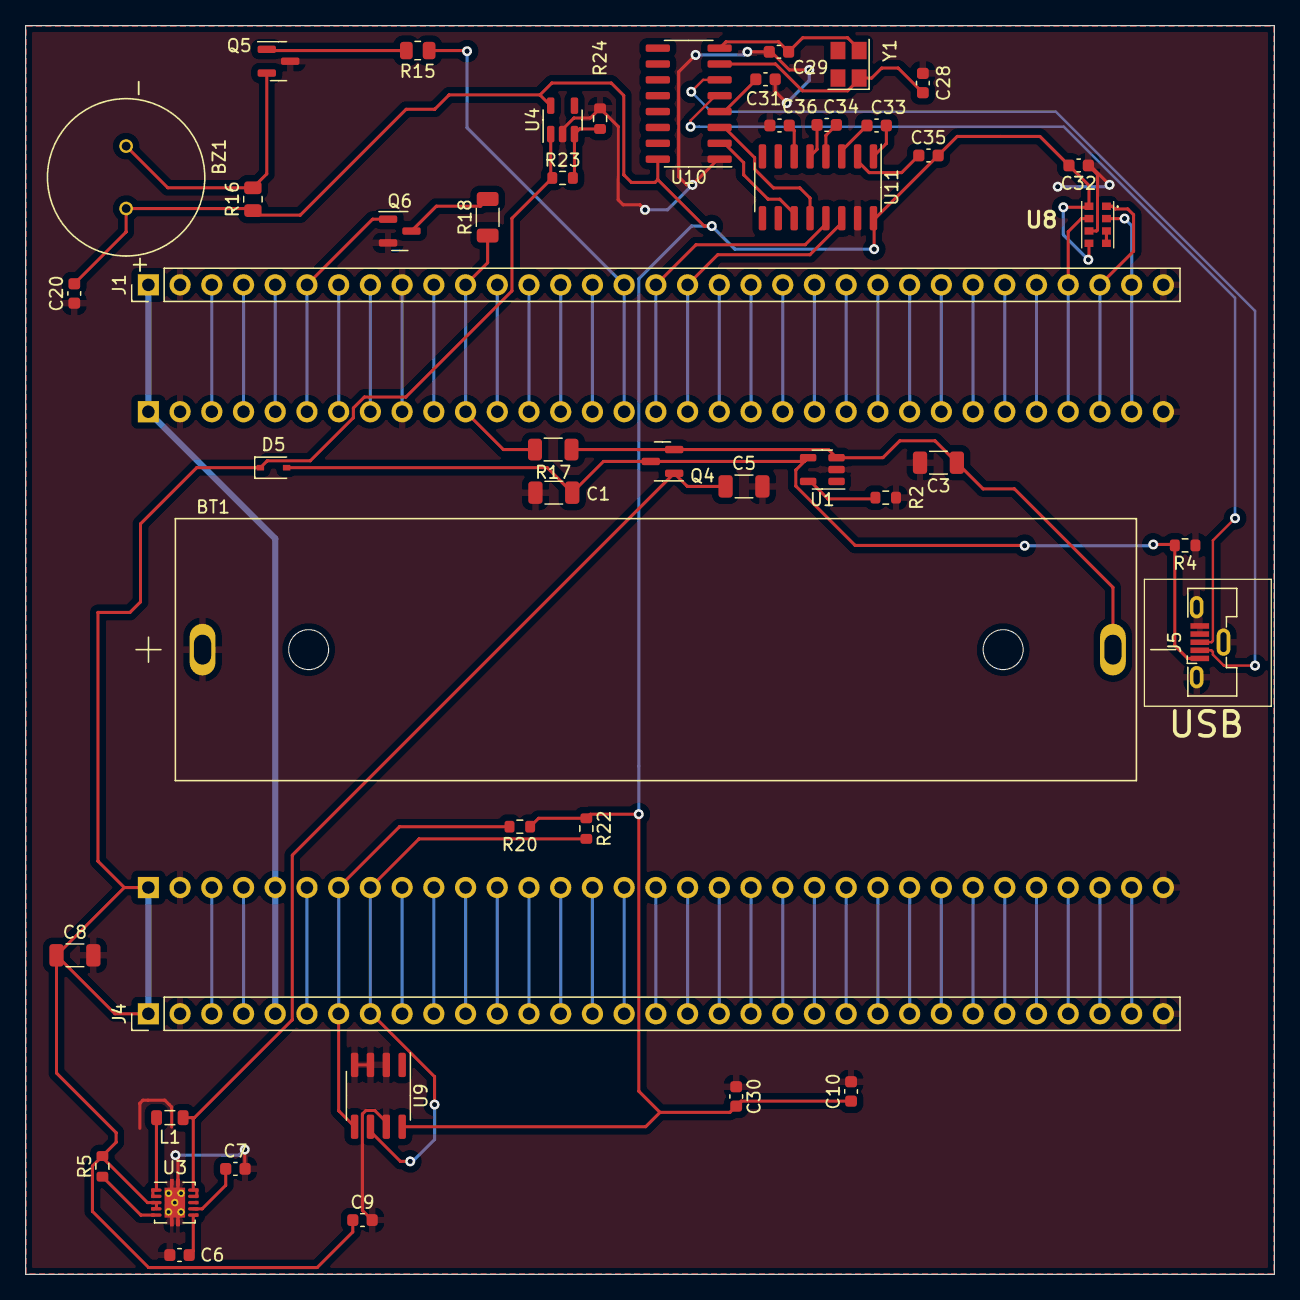
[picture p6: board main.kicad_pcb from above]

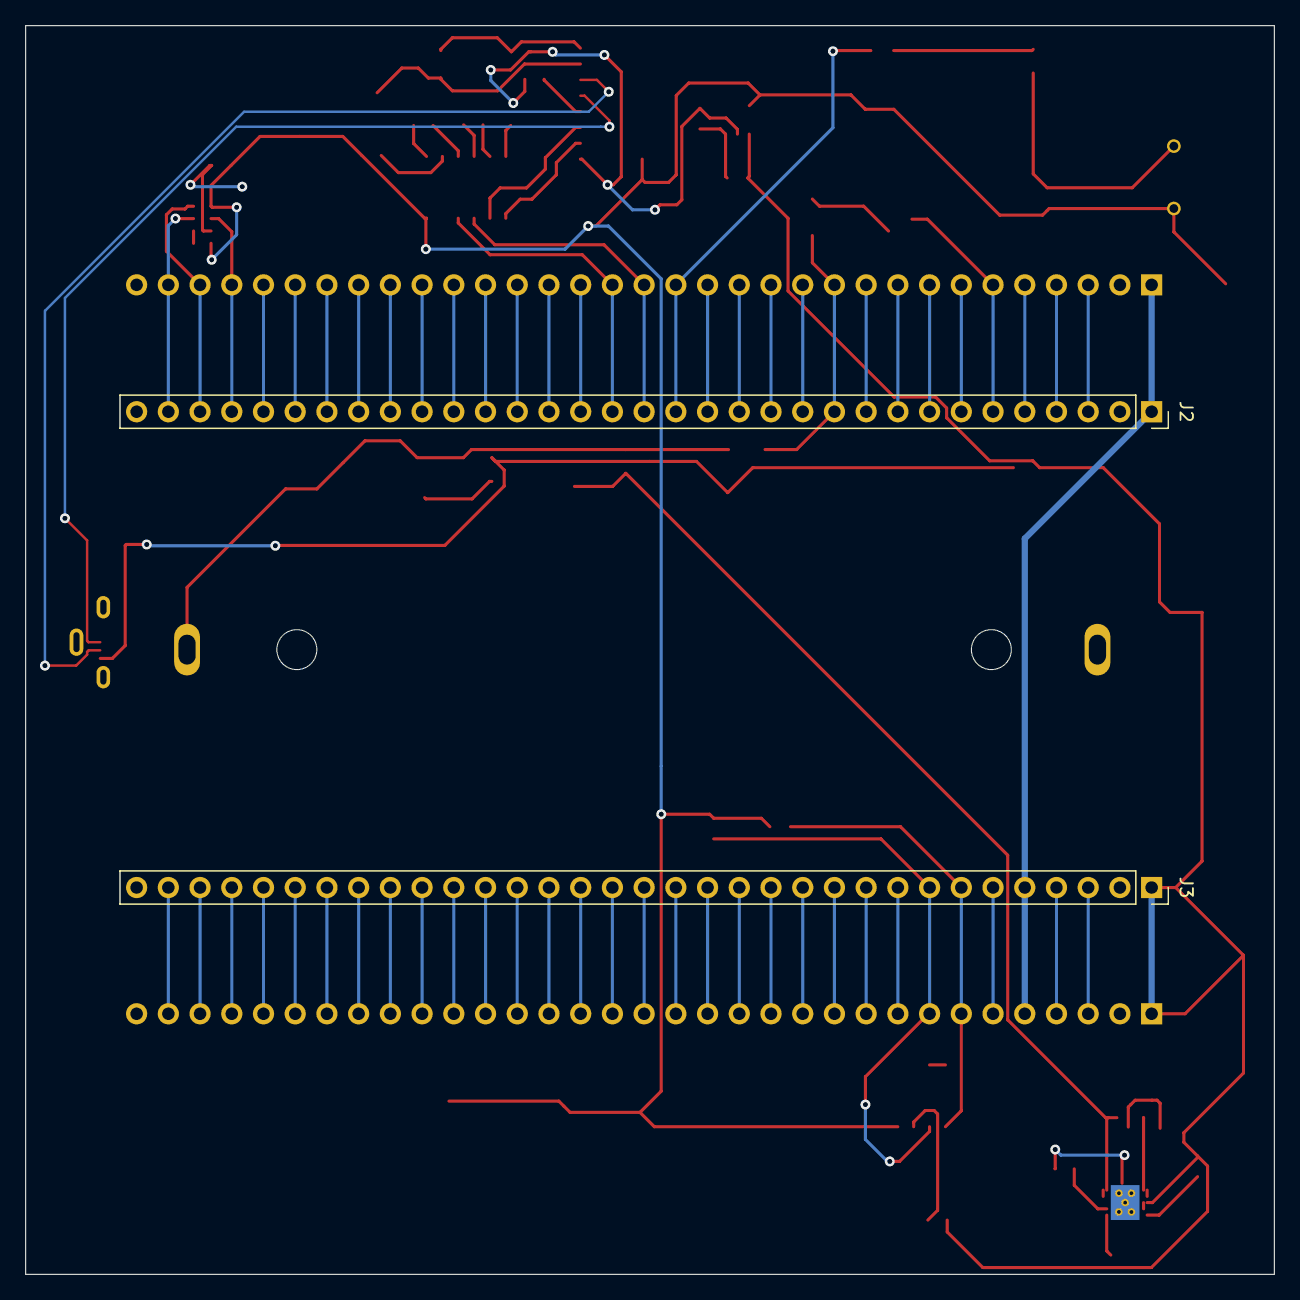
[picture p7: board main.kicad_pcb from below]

Board: 2 copper layers, 100.0 x 100.0 mm, 49 parts (2 on the bottom side), 88 nets.

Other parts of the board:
D5: D_Schottky; D_SOD-323

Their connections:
+5V: D5.1 (K); also elsewhere on the board
unnamed 66: D5.2 (A); also elsewhere on the board
